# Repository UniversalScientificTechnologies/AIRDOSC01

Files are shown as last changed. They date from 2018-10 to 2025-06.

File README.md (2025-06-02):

# AIRDOSC01B - AIRDOS dosimeter with scintillator-based sensor
*AIRDOS-C Scintillation detector of ionizing radiation with a full production specification available. The device can be further modified according to specific requirements. The character of its construction makes it suitable for placement into UAVs.*

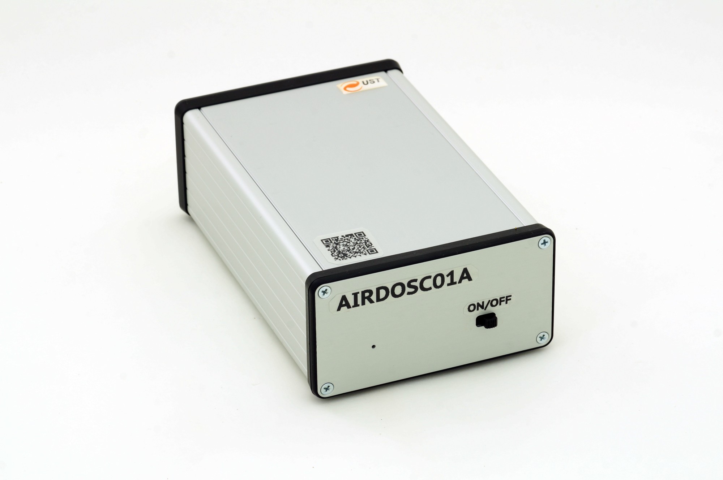
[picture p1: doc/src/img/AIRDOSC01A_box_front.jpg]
AIRDOS-C front panel


**Technical parameters are the following:**

* Detection element: scintillating crystal integrated with [SiPM](https://en.wikipedia.org/wiki/Silicon_photomultiplier)
* More than 90 days of autonomous operation powered by a lithium battery
* Data memory: SD card
* Data logs contain the energy and time of each event
* Logging periodicity: 10 s (dead time 2 s)
* Time resolution: 20 us
* Accuracy of event’s time: 500 ns
* Dimensions: 57 x 107 x 167 mm
* Mass in operating condition (including batteries) 1 kg
* Open-source HW and SW
* Device status indicator: LED on panel
* Airborne GPS parameters (measurement altitude verified up to 36km a.m.s.l.)

Since 2023, AIRDOSC has been discontinued. Please consider a newer [UST dosimeter series](https://www.ust.cz/UST-dosimeters/). 

**Device block diagram**
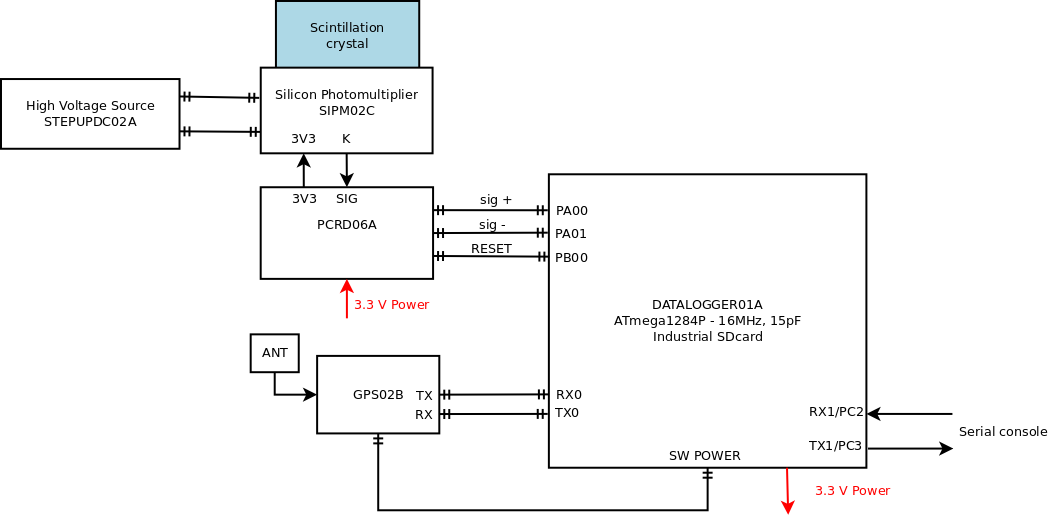
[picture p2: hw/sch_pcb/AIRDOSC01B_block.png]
AIRDOSC01B block diagram


**Production data of electronic modules**

* [STEPUPDC02A](https://github.com/mlab-modules/STEPUPDC02)
* [SIPM02C](https://github.com/mlab-modules/SIPM02) known as "AIRDOSC01A_PCB01C"
* [PCRD06A](https://github.com/mlab-modules/PCRD06)
* [GPS01B](https://www.mlab.cz/module/GPS01B)
* [DATALOGGER01A](http://mlab.cz/module/DATALOGGER01A)

Relevant scientific papers

* [CHARACTERISATION OF AIRDOS-C DETECTOR FOR MEASUREMENT OF HIGH-ENERGY EVENTS IN THE ATMOSPHERE](https://academic.oup.com/rpd/article-abstract/198/9-11/604/6672998?redirectedFrom=fulltext&login=false)

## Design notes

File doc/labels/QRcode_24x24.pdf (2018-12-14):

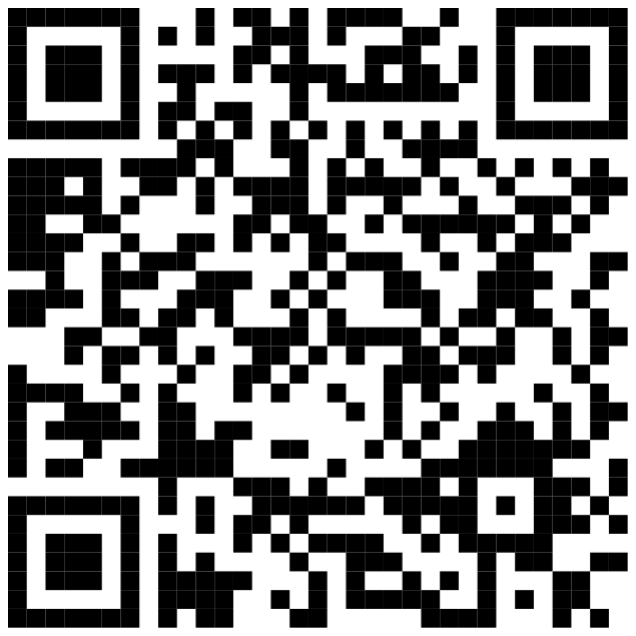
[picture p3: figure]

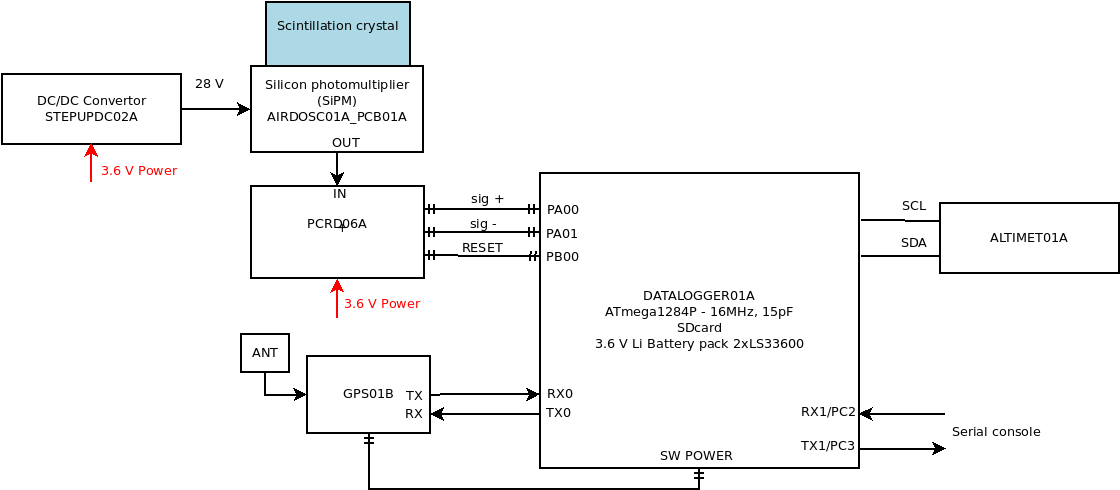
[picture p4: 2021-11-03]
doc/AIRDOSC_blocks.png

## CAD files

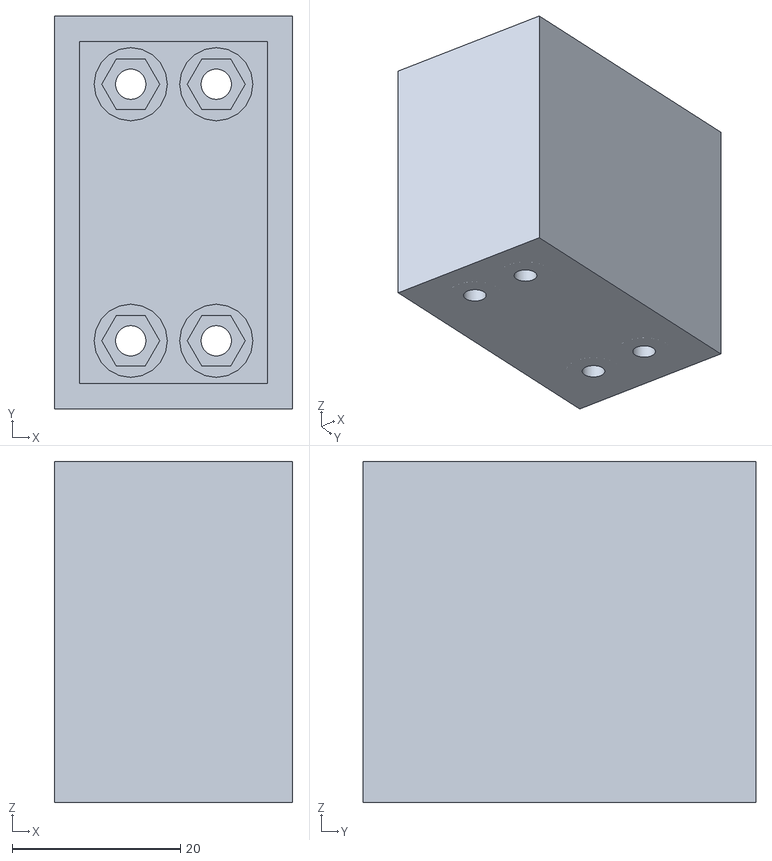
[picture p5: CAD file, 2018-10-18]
hw/cad/SIPMBOX01A/amf/SIPMBOX01A.stl
28.3 x 46.6 x 40.5

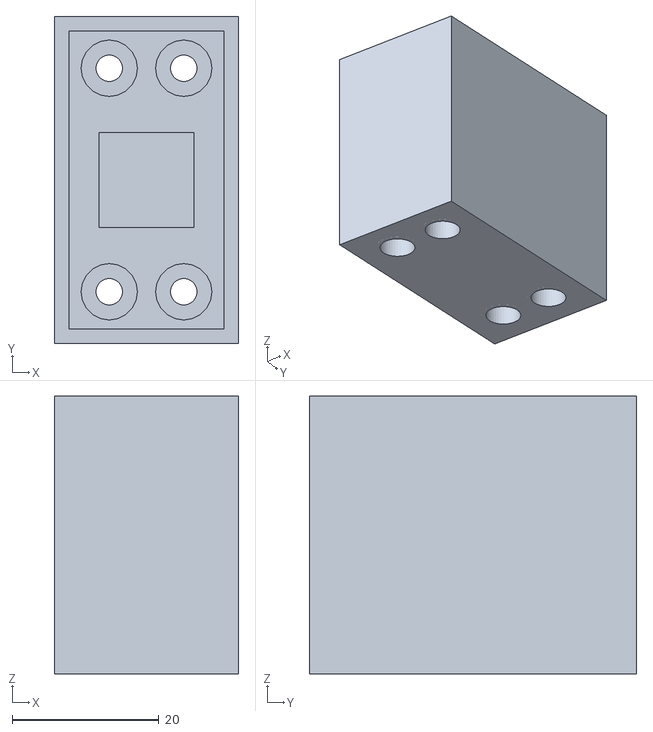
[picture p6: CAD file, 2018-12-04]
hw/cad/SIPMBOX01B/amf/SIPMBOX01B.stl
25.1 x 44.6 x 37.9

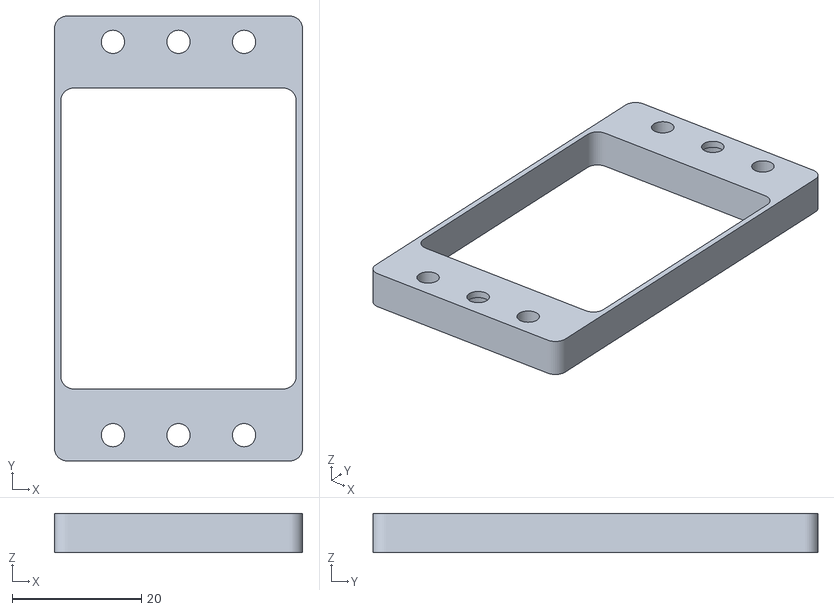
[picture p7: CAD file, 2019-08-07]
hw/cad/SIPMBOX02B/amf/SIPMBOX01C_D07.stl
38.5 x 69.0 x 6.10

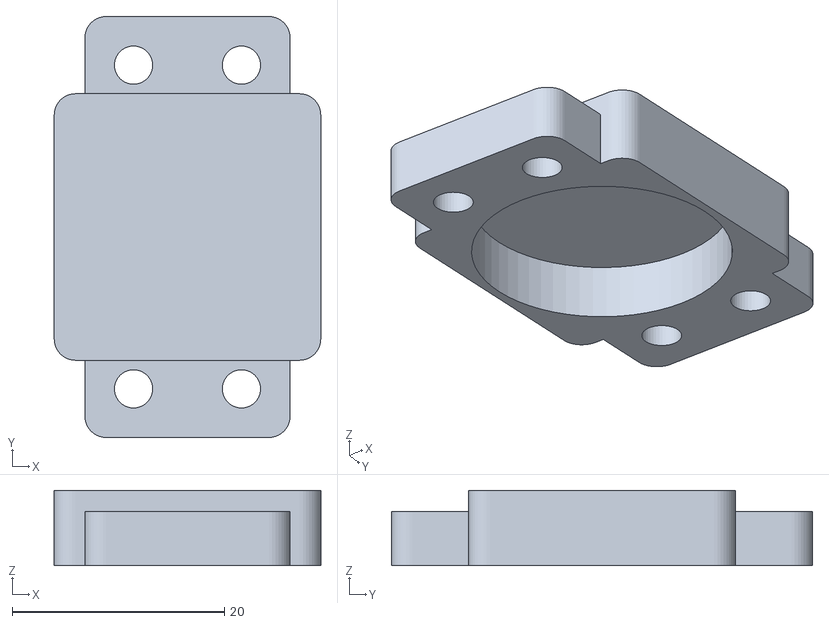
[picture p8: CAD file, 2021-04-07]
hw/cad/SIPMBOX02B/print_data/NaITl_big.stl
25.1 x 39.6 x 7.10

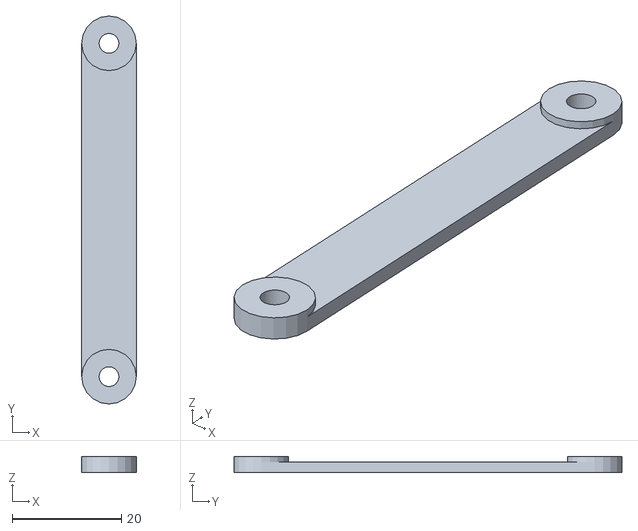
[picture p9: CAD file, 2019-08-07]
hw/cad/SIPMBOX02B/amf/SIPMBOX01C_D08.stl
10.0 x 71.0 x 3.00

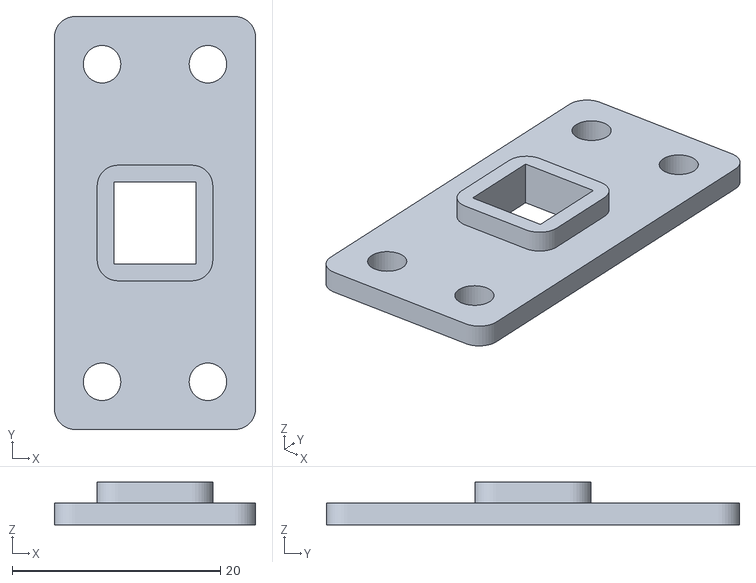
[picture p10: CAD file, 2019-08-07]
hw/cad/SIPMBOX02B/amf/SIPMBOX01C_D06.stl
19.3 x 39.6 x 4.10

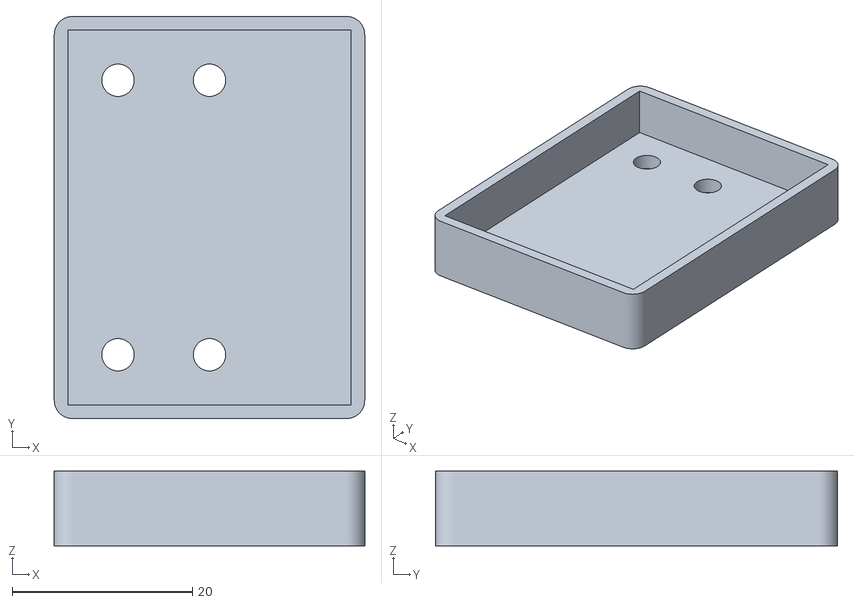
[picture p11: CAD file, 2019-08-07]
hw/cad/SIPMBOX02B/amf/SIPMBOX01C_D02.stl
34.5 x 44.6 x 8.30

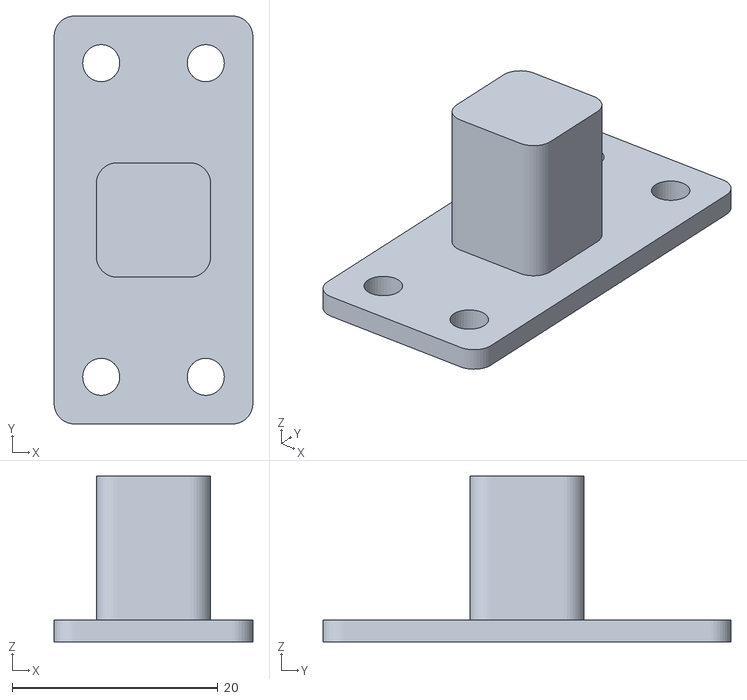
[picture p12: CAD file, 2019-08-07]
hw/cad/SIPMBOX02B/amf/SIPMBOX01C_D01.stl
19.3 x 39.6 x 16.1

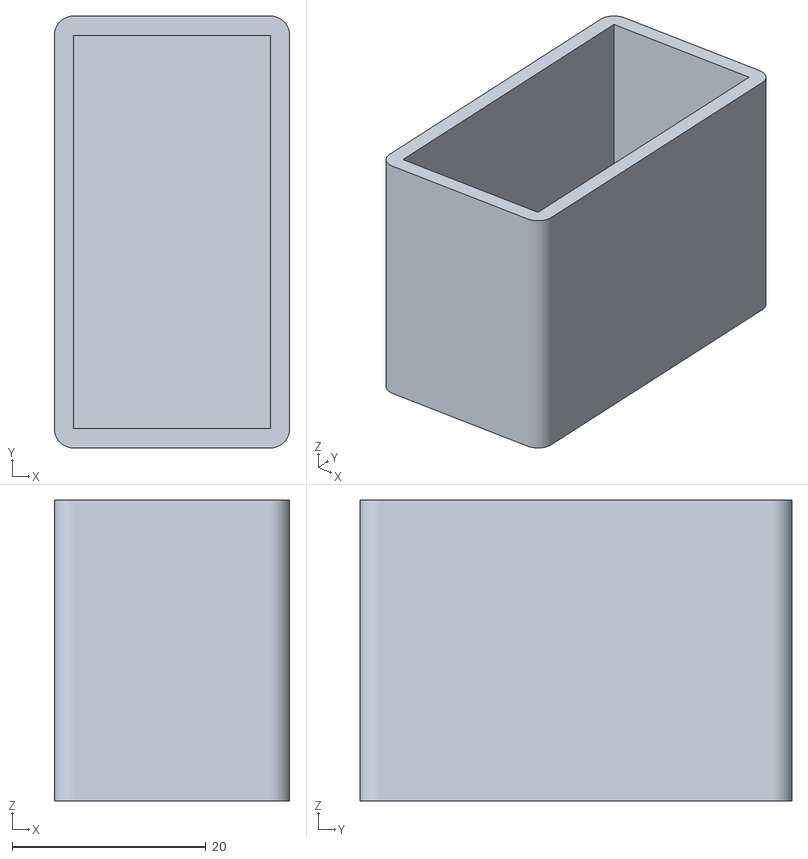
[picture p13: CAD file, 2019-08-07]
hw/cad/SIPMBOX02B/amf/SIPMBOX01C_D03.stl
24.3 x 44.6 x 31.1

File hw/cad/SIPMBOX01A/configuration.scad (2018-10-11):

$fn=40; // model faces resolution.

//OBECNE PARAMETRY 
//----------------------------------------------------------------
//----------------------------------------------------------------

vyska_krystalu=24;
zakladna_krystalu_x=12;
zakladna_krystalu_y=12;
sila_steny=3;
vyska_zapusti_pro_PCB=10; //výčka krycího matriálu pro PCB a zároveň pro vytvoření vany pro zalití silikonem, kvůli světlotěsnoti.
vyska_SIPM_nad_PCB=4; //víška celého SIPM senzoru
tolerance_pro_dotazeni_k_SIPM=-0.5; // kvůli dotažení krystalu k SIPM
velikost_modulu_x=2; //počet der
velikost_modulu_y=4;
rotec_der_modulu=10.16;

vyska_matky=3;
sirka_matky=6.7;
prumer_sroubu=3.4;

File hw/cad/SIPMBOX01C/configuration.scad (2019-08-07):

$fn=40; // model faces resolution.

//OBECNE PARAMETRY 
//----------------------------------------------------------------
//----------------------------------------------------------------

vyska_krystalu=24;
vyska_sipm=2;
presah_krystalu=6;
rezerva_nad_krystalem=5;
vyska_drzaku_krystalu=vyska_krystalu-presah_krystalu-2;

hrana_krystalu=6; //čistá hrana

zakladna_krystalu_x=7.9; //0.8mm rezerva hrana SIPM je 7mm
zakladna_krystalu_y=7.9;
sila_steny=1.6;
sila_materialu_zakladny=2;


vyska_zapusti_pro_PCB=0; //výčka krycího matriálu pro PCB a zároveň pro vytvoření vany pro zalití silikonem, kvůli světlotěsnoti.
vyska_SIPM_nad_PCB=2.4; //výška celého SIPM senzoru
tolerance_pro_dotazeni_k_SIPM=-0.5; // kvůli dotažení krystalu k SIPM
velikost_modulu_x=2; //počet der
velikost_modulu_y=4;
rotec_der_modulu=10.16;

vyska_matky=3;
sirka_matky=6.7;
prumer_sroubu=3.4;
prumer_hlavy_sroubu=6;
vyska_hlavy_sroubu=5;

//Pro díl SIPMBOX01C_D02
D02_velikost_modulu_x=3; //počet der
D02_velikost_modulu_y=4;
D02_vyska_bocniho_prekryvu=6.2;

//Pro díl SIPMBOX01C_D07
D07_vyska=6;

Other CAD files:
hw/cad/SIPMBOX01B/configuration.scad
hw/cad/SIPMBOX02A/configuration.scad
hw/cad/SIPMBOX01A/print_data/SIPMBOX01A.scad
hw/cad/SIPMBOX01A/src/SIPMBOX01A.scad
hw/cad/SIPMBOX01B/assembly.scad
hw/cad/SIPMBOX01B/src/SIPMBOX01B.scad
hw/cad/SIPMBOX01C/assembly.scad
hw/cad/SIPMBOX02A/src/NaITl_big.scad
hw/cad/SIPMBOX02B/assembly.scad
hw/cad/SIPMBOX02B/configuration.scad
hw/cad/SIPMBOX02B/print_data/SIPMBOX01C_D01.scad
hw/cad/SIPMBOX02B/print_data/SIPMBOX01C_D02.scad
hw/cad/SIPMBOX02B/print_data/SIPMBOX01C_D03.scad
hw/cad/SIPMBOX02B/print_data/SIPMBOX01C_D05.scad
hw/cad/SIPMBOX02B/print_data/SIPMBOX01C_D06.scad
hw/cad/SIPMBOX02B/print_data/SIPMBOX01C_D07.scad
hw/cad/SIPMBOX02B/print_data/SIPMBOX01C_D08.scad
hw/cad/SIPMBOX02B/src/NaITl.scad
hw/cad/SIPMBOX02B/src/NaITl_big.scad
hw/cad/SIPMBOX02B/src/SIPMBOX01C.scad
hw/cad/SIPMBOX02B/src/SIPMBOX01C_D04.scad

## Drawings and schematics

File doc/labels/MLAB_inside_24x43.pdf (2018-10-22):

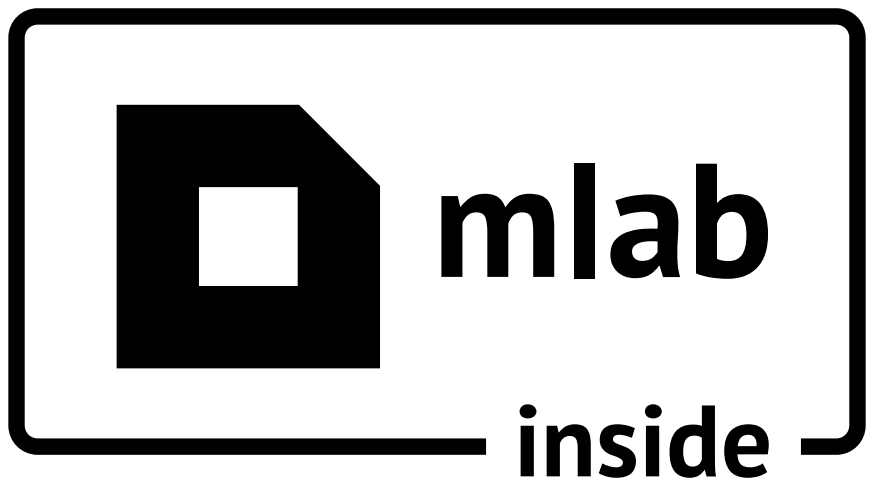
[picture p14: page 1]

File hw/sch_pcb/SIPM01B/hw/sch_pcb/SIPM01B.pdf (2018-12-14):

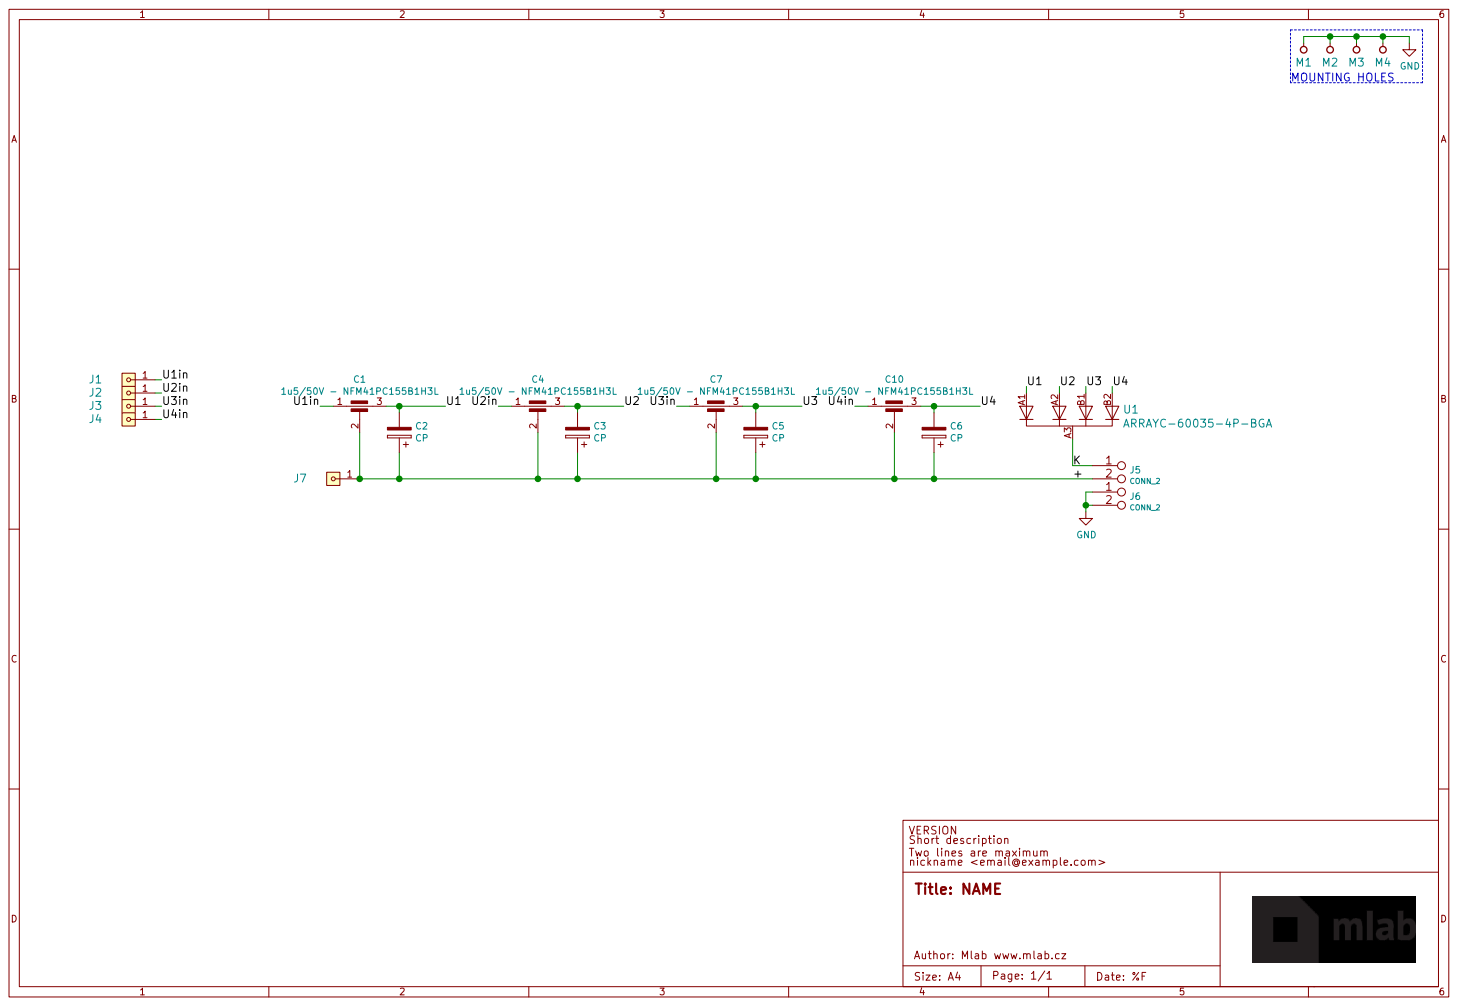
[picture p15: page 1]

VERSION
Short description
nickname <email@example.com>

Two lines are maximum

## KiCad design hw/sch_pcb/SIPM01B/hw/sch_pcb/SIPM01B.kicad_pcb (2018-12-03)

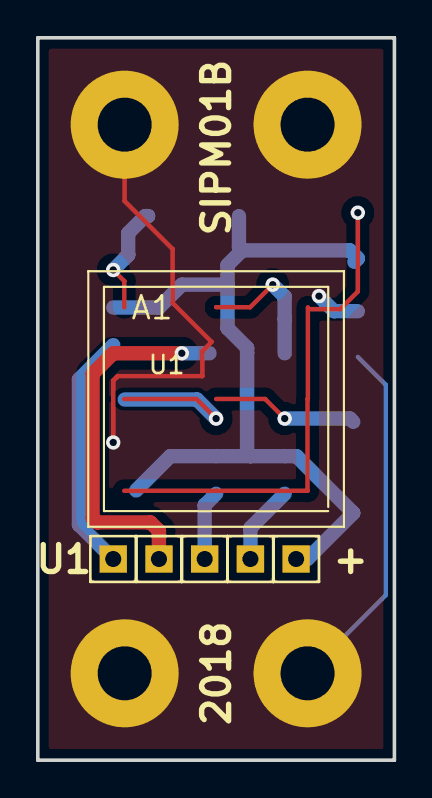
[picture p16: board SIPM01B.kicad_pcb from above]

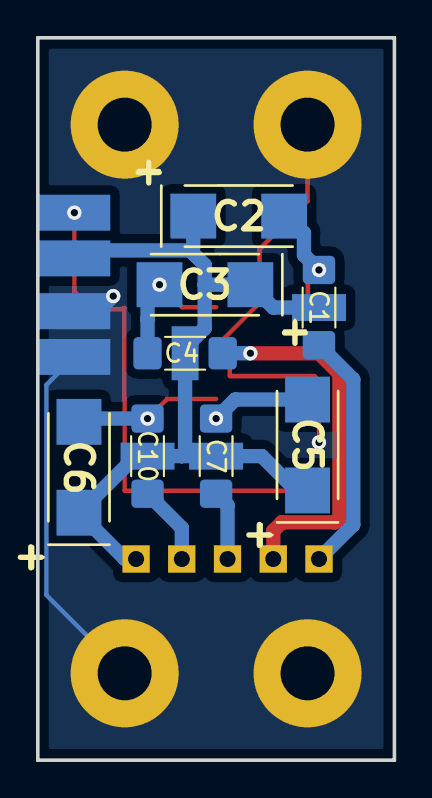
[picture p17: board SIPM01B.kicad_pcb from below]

Board: 2 copper layers, 19.8 x 40.1 mm, 20 parts (10 on the bottom side), 11 nets.

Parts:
C1, C4, C7, C10: 1u5/50V - NFM41PC155B1H3L; FIR_1806
C2, C3, C5, C6: CP; TantalC_SizeC_Reflow
J1, J2, J3, J4, J7: HEADER_1x01; Straight_1x01
J5, J6: CONN_2; SMD_1_2_4x2
M1, M2, M3, M4: HOLE; MountingHole_3mm
U1: ARRAYC-60035-4P-BGA; ArrayC-60035-4P-BGA

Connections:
/+: C1.2, C2.1, C3.1, C4.2, C5.1, C6.1, C7.2, C10.2, J5.2, J7.1
/K: J5.1, U1.A3, U1.B3, U1.C1, U1.C2, U1.C3
/U1: C1.3, C2.2, U1.A1
/U1in: C1.1, J1.1
/U2: C3.2, C4.3, U1.A2
/U2in: C4.1, J2.1
/U3: C5.2, C7.3, U1.B1
/U3in: C7.1, J3.1
/U4: C6.2, C10.3, U1.B2
/U4in: C10.1, J4.1
GND: J6.1, J6.2, M1.1, M2.1, M3.1, M4.1

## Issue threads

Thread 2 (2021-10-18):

AIRDOSC01A_PCB01B - 28 V power connector

kaklik, 2021-10-18:
Napájecí konektor pro 3.3V a pro 28V je identický. Může tak snadno dojít k záměně, která povede ke zničení modulu.

Navrhoval bych 28V konektor vyměnit za 4 pinovou variantu.

Je nutné mít zdroj vysokého napětí oddělený od tohoto modulu? Nelze vysoké napětí vyrobit rovnou na izolované a třeba i stíněné části tohoto PCB z jednoho vstupního napětí?

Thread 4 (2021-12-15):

Dokumentace

kaklik, 2021-12-15:
Modul SiPM má v této konstrukci již několik variant. Jak je vidět ve [složce hw](https://github.com/UniversalScientificTechnologies/AIRDOSC01/tree/AIRDOSC01A/hw/sch_pcb).

Zacházení s verzemi ale vede k tomu, že není jasné co je aktuální verze. Například v konstrukci GEODOSu se používá PCB [AIRDOSC01A_PCB01B](https://github.com/UniversalScientificTechnologies/AIRDOSC01/tree/AIRDOSC01A/hw/sch_pcb/AIRDOSC01A_PCB01B). Přitom by zřejmě bylo logičtější zachovat původní název a vytvořit například modul SIPM02A. Uvnitř [modulů MLAB](https://github.com/MLAB-modules). Důsledky aktuálního stavu jsou:

- V zařízení GEODOS lze jen těžko odkázat na konkrétní dokumentaci  AIRDOSC01A_PCB01B (nelze ji vložit jako submodul)
-  Nejde snadno udržovat issues ke konstrukci AIRDOSC01A_PCB01B, protože nemá samostatný repozitář
- Nelze tuto konstrukci forknout a použít v dalších zařízeních.

kaklik, 2022-04-02:
Pokusil jsem se to vyřešit vytvořením samostatného repozitáře [SIPM](https://github.com/mlab-modules/SIPM01) v [mlab-modules](https://github.com/mlab-modules). Jenže se při přesunu hnad prvního modulu SIPM01A ukázalo, že zároveň [existuje i v repozitáři Modules](https://github.com/MLAB-project/Modules/tree/master/sensors/SIPM01A).
Přesunutí tak není jednoduché, neboť oba moduly se stejným názvem mají rozdílnou historii změn

- [Historie SIPM v MLAB/Modules](https://github.com/MLAB-project/Modules/commits/master/sensors/SIPM01A)
- [Historie SIPM v UST/AIRDOSC01](https://github.com/UniversalScientificTechnologies/AIRDOSC01/commits/AIRDOSC01A/hw/sch_pcb/SIPM01A)

kaklik, 2022-04-02:
Tak jsem částečně uklidil vytvořením nových MLAB repositářů s moduly [SIPM02](https://github.com/mlab-modules/SIPM02) a [SIPMPOWER01](https://github.com/mlab-modules/SIPMPOWER01). Nedovedu ale vyřešit problém s dokumentací SIPM01.

ChroustJan, 2022-04-04:
SIPM01 není možné sloučit. Jsou to dva rozdílné moduly. Ten v MLAB repozitáři nemá výrobní data. Očekával bych tedy, že se ani nevyráběl. Proto bych navrhoval, pokud chceme SIPM01 z UST přesunout do MLAB modulů ho přejmenovat na SIPM03. A u UST SIPM01 zachovat jeho název. SIPM01 v UST AIRDOSC01 má ještě verzi SIPM01B.

kaklik, 2022-04-04:
> SIPM01 není možné sloučit. Jsou to dva rozdílné moduly. Ten v MLAB repozitáři nemá výrobní data. Očekával bych tedy, že se ani nevyráběl. Proto bych navrhoval, pokud chceme SIPM01 z UST přesunout do MLAB modulů ho přejmenovat na SIPM03. A u UST SIPM01 zachovat jeho název. SIPM01 v UST AIRDOSC01 má ještě verzi SIPM01B.

Tuhle úvahu nechápu. Pokud SIPM01 v repozitáři AIRDOSC nahrahuje ten modul, který je v [MLAB modules](https://github.com/MLAB-project/Modules/commits/master/sensors/SIPM01A) o kterém navíc tvrdíš, že se nikdy nevyráběl. Tak nevidím žádný důvod ho přejmenovávat. Protože název SIPM01A i SIPM01B je kompatibilní s MLAB a taktéž návrh toho modulu je MLAB kompatibilní. Tudíž to vidím tak, že zdejší modul v AIRDOSC nahrazuje ten původní v MLAB, který se asi nějakým omylem stal balastem v repozitáři.

ChroustJan, 2022-04-04:
Navrhuji ten MLAB balast přejmenovat na SIPM03. Přijde mi škoda ten návrh zahodit. Stál nějaký čas a nevím zda se někdy nehodí. Bila to iterace.

kaklik, 2022-04-04:
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

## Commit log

2018-09-28 Návrh PCB
    [SIPM01A.csv, SIPM01A.kicad_pcb, SIPM01A.sch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]
2018-10-11 Krabička pro zatemnění krystalu.
    [SIPMBOX01A.scad, SIPMBOX01A.stl, assembly.scad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]
2018-10-12 Drzak PCRD
    [PCDRHOLDER01A.scad, PCDRHOLDER01A.stl, PCRDHOLDER01A.scad]
2018-10-18 Rozříšení držáku pro krystal.
    [SIPMBOX01A.scad, SIPMBOX01A.stl, assembly.scad]
2018-12-03 Nový PCB pod SIPM
    [SIPM01B.kicad_pcb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]
2018-12-04 Krabička pro krystal
    [SIPMBOX01B.scad, SIPMBOX01B.stl, assembly.scad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]
2019-01-03 Odebrani nevhodneho drzaku
    [PCDRHOLDER01A.scad, PCDRHOLDER01A.stl, PCRDHOLDER01A.scad]
2019-07-18 Zmena parametru
    [SIPMBOX01C.scad, SIPMBOX01C_D05.stl]
2019-08-07 Edit 3D model
    [SIPMBOX01C.scad, SIPMBOX01C_D01.stl, SIPMBOX01C_D02.stl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]
2020-06-12 holder for NaITl crystal
    [NaITl.scad, SIPMBOX01C.scad, SIPMBOX01C_D01.scad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]
2021-02-11 Úprava pouzdra SiPM
    [AIRDOSC01A_PCB01A.kicad_sch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]
2021-02-24 Přiřazení součástek
    [AIRDOSC01A_PCB01B.kicad_sch]
2021-03-14 holder for new crystal from Ukraine
    [NaITl.scad, NaITl_big.scad, NaITl_big.stl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]
2021-04-03 Úprava hodnot ve schématu.
    [AIRDOSC01A_PCB01B.kicad_pcb, AIRDOSC01A_PCB01B.kicad_sch]
2021-07-20 Edit PCB
    [AIRDOSC01A_PCB01C-B_Cu.gbr, AIRDOSC01A_PCB01C-B_Mask.gbr, AIRDOSC01A_PCB01C-Edge_Cuts.gbr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]
2021-10-18 Improve documentation for PCB01 SiMP holder.
2021-11-03 figures for publication
    [AIRDOSC01A_PCB01C._forpub.kicad_sch]
2021-12-19 Fix disfunctional assembly.
    [assembly.scad]
2022-01-03 Change R10 from 6k8 to 12k
    [AIRDOSC01A_PCB01C.csv, AIRDOSC01A_PCB01C.kicad_pcb, AIRDOSC01A_PCB01C.kicad_sch]
2022-04-02 Cleanup the documentation and move of designs to separate repositories #4 https://github.com/mlab-modules/SIPMPOWER01 https://github.com/mlab-modules/SIPM02
    [AIRDOSC01A_PCB01A.kicad_pcb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]
